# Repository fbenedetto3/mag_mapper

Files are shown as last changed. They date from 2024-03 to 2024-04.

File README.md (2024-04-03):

# MagField-MT Documentation

## Overview
MagField-MT is a low-cost magnetic field mapping platform that can be easily assembled using easily avaliable commercially avaliable components. The plaform is constructed using a Ender 3 (or similar) 3d printer and a Metrolab MagVector MV2 Three-Axis Hall Effect Sensor, and controlled by a computer via a LabView interface. 

## Hardware
All necessary hardware may be printed using the requisite Ender 3 3D printer. [Hardware files](Sensor%20Mounting%20Hardware) are provided in an .stl format for use with any slicing program and .sldprt format to enable modification. M3-25mm bolts and M3 nuts are required to attach the sensor to the mount. 

## Downloading the Magnetic Field Mapper LabVIEW Program

## Using Magnetic Field Mapper LabVIEW Program
To establish a connection between the Arduino, 3D printer, and the LabVIEW program, select the proper COM port for each device and input it into the COM port selection for each device. Select initialize to establish a COM port connection. Ensure the proper COM ports are selected in the event of an error and initialize again.

Custom commands can be sent to the printer, in addition to movements in the movement pane. The distance travelled per movement can be configured in the “Distance” selection and the movement speed of all movements of the printer can be configured in the “Speed” selection. The pathing file can be selected in the “Path File Location” dropdown. Ensure that the file selected is a .csv file with comma delimiters. A MATLAB program that generates pathing files is included in GitHub, but custom paths can easily be generated by the user. The mapping path can be displayed for the user in the mapping path pane.

Before running the mapping scan, ensure that a text file that is empty is selected as previous data will be overwritten. To run the mapping program, press “RUN SCAN”, at which point the program will commence. To exit the mapping program, select “EXIT SCAN”. The same button can also be selected to exit the mapping program not during a scan.

## MATLAB Path Generator
Generates a csv file with magnetic field mapper gird. Inputting gridGenerator(x,y,z,xres,yres,zres) will output a path with resolution being specified for every cardinal direction. Inputting gridGenerator(x, y, z, xres, yres, zres, xCenter, yCenter, zCenter will output a grid with with shifted coordinates around a specified center. This is useful when a scan needs to surround a specific sample. Running the function with no variables will prompt the function to ask user to input xyz scan size and resolution.

## Proper Printing MID
This program uses instrument drivers developed by Jón Schone of Proper Printing. The Marlin Instrument Drivers can be found at https://github.com/properprinting/PPC. The LabVIEW folder contains the drivers, but they can be optionally installed into the LabVIEW program files for use in other programs.

## Arduino Code
The latest version of the program uses [MV2_analog_Mean_Var.ino](Arduino%20Code/MV2%20Analog%20Mean%20Var/MV2_analog_Mean_Var). It operates by calculating the mean and variance of 30 readings after receiving an “M” command over the serial port. The number of readings can be changed in the code by changing the variable “nReads” if the user desires. Additional programs are in the GitHub that automatically send magnetic field data while on, which can be useful during debugging of the sensor. Additional documentation of the sensor is available on https://www.metrolab.com/products/magvector-mv2-magnetometer/.

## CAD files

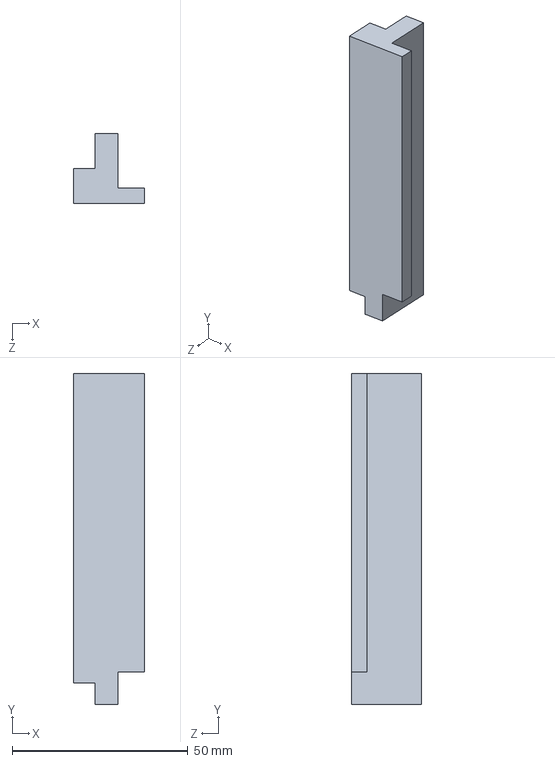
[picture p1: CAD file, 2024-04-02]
Sensor Mounting Hardware/Safety Barrier.SLDPRT
20.1 x 94.2 x 20.0 mm

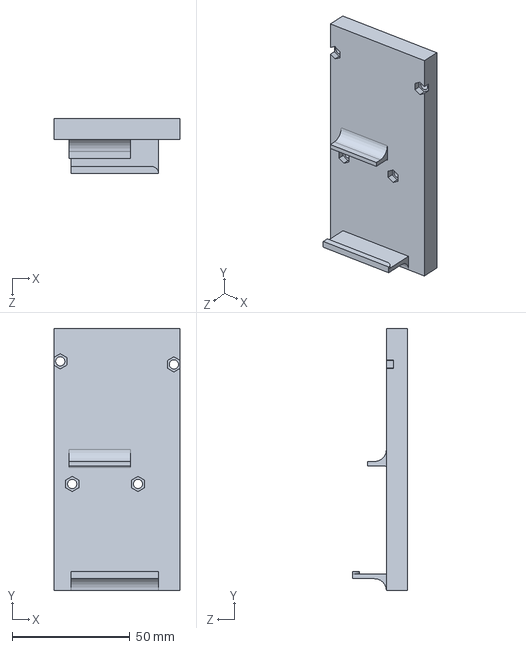
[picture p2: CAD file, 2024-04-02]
Sensor Mounting Hardware/Mount V2.2.SLDPRT
53.4 x 111.3 x 23.4 mm

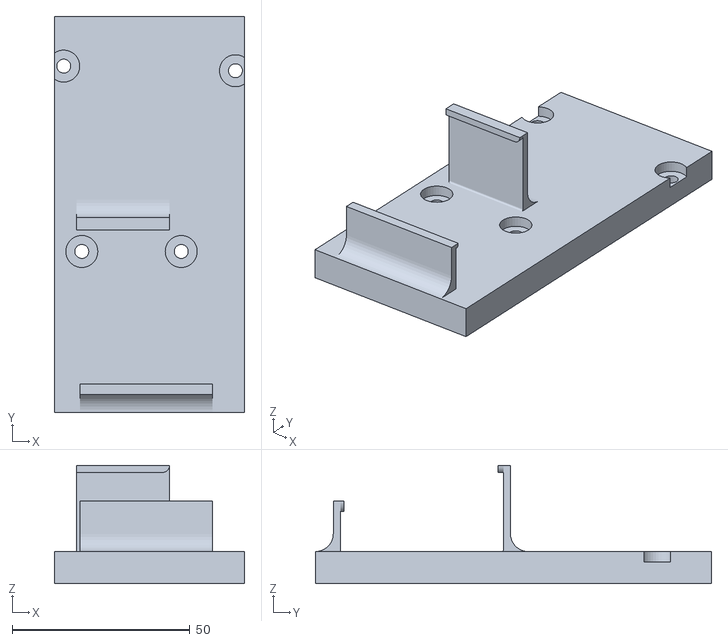
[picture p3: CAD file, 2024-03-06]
Sensor Mounting Hardware/Mount V2.1.STL
53.4 x 111.3 x 33.2

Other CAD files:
Sensor Mounting Hardware/Safety Barrier V1.1.STL

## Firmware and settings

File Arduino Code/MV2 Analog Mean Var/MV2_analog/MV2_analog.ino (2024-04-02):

/*   MV2_analog.ino
 * 
 *   example code how to set and read analog data from 
 * 
 *   METROLAB MV2 3 axis Hall sensor: 
 *   
 *   code for standalone operation 
 *   with an Arduino MEGA or UNO (generic design)
 *   
 *   I did a coarse calibration versus another Hall probe and the values seem to be correct within 5% or better.
 *   Becasue I had to magnetic shield of suitable size I could not check the offsets.
 *   There is a systemtatic difference of 0.5 relative to the calibration data in Table 6 (5V),  
 *   addionally the temperature is also somewhat odd, couldn't calibrate this much.
 *   
 *   Therefore, this code is just an example how to get started (reading all three field components with 10bit resolution
 *   and manually adjustable range). Extended range and other temp. compensations were not tried, but I'm sure you will 
 *   figure out if needed.
 *   
 *   PS: These is also a code for digital operation
 * 
 *   (c) P. Blümler, Physics Uni Mainz, Germany 2022
 *       bluemler@uni-mainz.de
 */
 
 #include <SPI.h> 


#define NDIGITAL_ANALOG_PIN     8
#define VDD_PIN                 A5 
#define A_BX_PIN                A0
#define A_BY_PIN                A1
#define A_BZ_PIN                A2
#define A_TEMPERATURE_PIN       A3
#define A_REF_PIN               A4
#define A_EMR_PIN               2
#define A_INV_PIN               4
#define A_LP_PIN                7

#define A_MA0_PIN               10  //pins on Arduino UNO
#define A_MA1_PIN               11
#define A_RA0_PIN               12
#define A_RA1_PIN               13

/*  
 *  #define A_MA0_PIN               53  //pins on Arduino MEGA
    #define A_MA1_PIN               51
    #define A_RA0_PIN               50
    #define A_RA1_PIN               52
 */

float Vref, Temp,RangeXY,RangeZ;
int ARi,Bxi,Byi,Bzi,Ti;
uint8_t range;

char strX[20]; //at least as long as # of char +1
char strY[20]; //are these too long/short. Idk but seems to work/not matter
char strZ[20]; 
char strVarX[20]; //at least as long as # of char +1
char strVarY[20]; //are these too long/short. Idk but seems to work/not matter
char strVarZ[20]; 
char buffer[50];

int nReads = 30;
float Bx[nReads];
float By[nReads];
float Bz[nReads];




char incomingByte = '0';

void setup() {
    //Configure common pins
    pinMode(NDIGITAL_ANALOG_PIN, OUTPUT);
    pinMode(VDD_PIN, INPUT);
    pinMode(A_BX_PIN, INPUT);
    pinMode(A_BY_PIN, INPUT);
    pinMode(A_BZ_PIN, INPUT);
    pinMode(A_TEMPERATURE_PIN, INPUT);
    pinMode(A_REF_PIN, INPUT);
    pinMode(A_INV_PIN, OUTPUT);
    //Configure option pins
    pinMode(A_MA0_PIN, OUTPUT);
    pinMode(A_MA1_PIN, OUTPUT);
    pinMode(A_RA0_PIN, OUTPUT);
    pinMode(A_RA1_PIN, OUTPUT);
    pinMode(A_LP_PIN, OUTPUT);
    pinMode(A_EMR_PIN, OUTPUT);
   
    digitalWrite(NDIGITAL_ANALOG_PIN, HIGH); //enable Analog mode
    // Initialize all other controls to LOW (logic 0)
    digitalWrite(A_INV_PIN, LOW);
    digitalWrite(A_MA0_PIN, LOW);
    digitalWrite(A_MA1_PIN, LOW);
    digitalWrite(A_RA0_PIN, LOW);
    digitalWrite(A_RA1_PIN, LOW);
    digitalWrite(A_LP_PIN, LOW);
    digitalWrite(A_EMR_PIN, LOW);
    Serial.begin(9600);
}

void AnalogSetOptions(uint8_t Options)  //Set options bits : RA0, RA1, MA0, MA1, LP, INV, EMR
{   digitalWrite(A_RA0_PIN, bitRead(Options, 0));
    digitalWrite(A_RA1_PIN, bitRead(Options, 1));
    digitalWrite(A_MA0_PIN, bitRead(Options, 2));
    digitalWrite(A_MA1_PIN, bitRead(Options, 3));
    digitalWrite(A_LP_PIN,  bitRead(Options, 4));
    digitalWrite(A_INV_PIN, bitRead(Options, 5));
    digitalWrite(A_EMR_PIN, bitRead(Options, 6));
}


void loop() {
        for (int i = 0; i < nReads; i++){
                // SELECT RANGE MANUALLY
        range=0;    // 0 = +/- 100 mT, 1 = +/- 300 mT, 2 = +/- 1 T, 3 = +/- 3 T

        //Serial.print(" >>> Analog Mode:   range: ");
        if (Serial)
        switch (range){
          case 0:
            RangeXY=18.18;  //range from table 6 (5V)
            RangeZ=20.73;
            //Serial.println("+/- 100 mT");
            break;
          case 1:
            RangeXY=6,27;  //range from table   6 (5V)
            RangeZ=7.04;
            //Serial.println("+/- 300 mT");
            break;
          case 2:
            RangeXY=1.89;  //range from table  6 (5V)
            RangeZ=2.13;
            //Serial.println("+/- 1000 mT");
            break;
            case 3:
          default:
            RangeXY=0.62;  //range from table  6 (5V)
            RangeZ=0.72;
            //Serial.println("+/- 3000 mT");
            break;
          }
          // here only the first 2 bits (RA0 and RA1) are set 
          AnalogSetOptions(range); // Set OPTIONS bits (RA0, RA1, MA0, MA1, LP, INV, EMR)



//Wait to see if read command is sent
 if (Serial.available() > 0) {
    // read the incoming byte:
    incomingByte = Serial.read();

    if (incomingByte == 'M') {


          ARi=analogRead(A_REF_PIN);
          Bxi=analogRead(A_BX_PIN);
          Byi=analogRead(A_BY_PIN);
          Bzi=analogRead(A_BZ_PIN);
          Ti=analogRead(A_TEMPERATURE_PIN);
          // conversion to voltages(without extended measuring range)
          Vref=float(ARi)/511*5000; // reference voltage [mV]
          
          // 10 bit Arduino ADC * 5000 mV and additional mV offset

          Bx[i] = float(Bxi-ARi-3.2)/511*5000/RangeXY/2;
          By[i] = float(Byi-ARi-4.5)/511*5000/RangeXY/2 ;
          Bz[i]=float(Bzi-ARi)/511*5000/RangeZ/2;
          Serial.println(Bx[i], 1);

      }
      float BxSum = 0;
      float BySum = 0;
      float BzSum = 0;
      float BxSumSq = 0;
      float BySumSq = 0;
      float BzSumSq = 0;

      for (int i = 0; i < nReads; i++){
        BxSum += Bx[i];
        BySum += By[i];
        BzSum += Bz[i];


      }

      float meanX = 0;
      float meanY = 0;
      float meanZ = 0;
      float varX = 0;
      float varY = 0;
      float varZ = 0;

      meanX = BxSum/nReads;
      Serial.print(meanX, 3);
      Serial.print(", ");
      meanY = BySum/nReads;
      Serial.print(meanY, 3);
      Serial.print(", ");
      meanZ = BzSum/nReads;
      Serial.print(meanZ, 3);
      Serial.println();
        BxSum = 0;
        BySum = 0;
        BzSum = 0;








      // for (int i = 0; i < nReads; i++){
      //   BxSumSq += (Bx[i] - meanX)*(Bx[i] - meanX);
      //   //Serial.println(BxSumSq,1);
      //   BySumSq += (By[i] - meanY)*(By[i] - meanY);
      //   BzSumSq += (Bz[i] - meanZ)*(Bz[i] - meanZ);
      // }
      // varX = BxSumSq/(nReads-1);
      // Serial.print(varX, 3);
      // Serial.print(", ");
      // varY = BxSumSq/(nReads-1);
      // Serial.print(varY, 3);
      // Serial.print(", ");
      // varZ = BxSumSq/(nReads-1);
      // Serial.println(varZ, 3);
      // dtostrf(meanX, -5, 7, strX); 
      //  dtostrf(meanY, -5, 7, strY); 
      //  dtostrf(meanZ, -5, 7, strZ); 
      //  dtostrf(meanX, -5, 7, strVarX); 
      //  dtostrf(meanY, -5, 7, strVarY); 
      //  dtostrf(meanZ, -5, 7, strVarZ); 
      //sprintf(buffer, "%s, %s, %s, %s, %s, %s", strX, strY, strZ, strVarX, strVarY, strVarZ);
       
    }
  }
}

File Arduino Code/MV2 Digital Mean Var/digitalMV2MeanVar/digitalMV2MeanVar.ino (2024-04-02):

/*   MV2_digital.ino
 * 
 *   example code how to set and read data from 
 * 
 *   METROLAB MV2 3 axis Hall sensor: 
 *   
 *   code for standalone operation 
 *   with an Arduino MEGA or UNO (generic design)
 *   
 *   I did a coarse calibration versus another Hall probe and the values seem to be correct within 5% or better.
 *   Becasue I had to magnetic shield of suitable size I could not check the offsets.
 *   The temperature is also somewhat odd, because the values given in the data sheet (table 10) gave strange values.
 *   
 *   Therefore, this code is just an example how to get started (reading all three field components with 16bit resolution
 *   and manually adjustable range). Extended range and other temp. compensations were not tried, but I'm sure you will 
 *   figure out if needed.
 *   
 *   PS: These is also a code for analog operation
 * 
 *   (c) P. Blümler, Physics Uni Mainz, Germany 2022
 *       bluemler@uni-mainz.de
 */
    const int xPin = A0; 
    const int yPin = A1;
    const int zPin = A2;
    float xZero = digitalRead(xPin);
    float yZero = digitalRead(yPin);
    float zZero = digitalRead(zPin);

#include <SPI.h> 
#define NDIGITAL_ANALOG_PIN     8
#define D_DR_PIN                2
#define D_INIT_PIN              7
#define D_CHIP_SELECT_PIN       10
#define D_SPI_MOSI                11
#define D_SPI_MISO              12
#define D_SPI_CLK               13

const byte READ = 0x1C;   //Read address MV2     
const byte WRITE = 0x2C;  //Write address MV2
float Temp,RangeXY,RangeZ;
uint16_t data;
int range_set;
byte RA_byte;

char strX[20]; //at least as long as # of char +1
char strY[20]; //are these too long/short. Idk but seems to work/not matter
char strZ[20]; 
char strVarX[20]; //at least as long as # of char +1
char strVarY[20]; //are these too long/short. Idk but seems to work/not matter
char strVarZ[20]; 
char buffer[50];

const int nReads = 30;
float Bx[nReads];
float By[nReads];
float Bz[nReads];

char incomingByte = '0';


void setup() {
    Serial.begin(9600);
    digitalWrite(NDIGITAL_ANALOG_PIN,LOW); //Select digital mode
    SPI.begin();
    pinMode(D_DR_PIN , INPUT);
    pinMode(D_CHIP_SELECT_PIN, OUTPUT);
    writeRegister(0xC1, 0x00);  //init
    writeRegister(0x2C, 0x2C);  //set to read Bx 3T 16 bit (to init)
    writeRegister(0x2D, 0x02);  //permanent MISO
    writeRegister(0x2E, 0x08);  //temp. comp 0
    delay(100); }
    

//little routine to read a SPI register 
uint16_t readRegister(byte Register, byte Value) {
   uint16_t result = 0;   // result to return
   uint16_t dataToSend = (Register << 8) | Value;
   digitalWrite(D_CHIP_SELECT_PIN, LOW);
   result = SPI.transfer16(dataToSend);
   digitalWrite(D_CHIP_SELECT_PIN, HIGH);
   return (result);}


//little routine to write a SPI register 
void writeRegister(byte Register, byte Value) {
   uint16_t dataToSend = (WRITE << 8) | Register ;
   digitalWrite(D_CHIP_SELECT_PIN, LOW);
   SPI.transfer16(dataToSend); //Send register location
   SPI.transfer(Value);  //Send value to record into register
   digitalWrite(D_CHIP_SELECT_PIN, HIGH);}
 
void loop() {
  float Bxs = 0;
  float Bys = 0;
  float Bzs = 0;
  // SELECT RANGE MANUALLY
  range_set=1; // 0 = +/- 100 mT, 1 = +/- 300 mT, 2 = +/- 1 T, 3 = +/- 3 T

  //Serial.print(" >>> Digital Mode:   range: ");
  
  switch (range_set){ //offsets need to be detemined experimentally
    case 0:
      RA_byte=0x00;
      RangeXY=267;  //range from table 10
      RangeZ=289;
     // Serial.println("+/- 100 mT");
      break;
    case 1:
      RA_byte=0x04;
      RangeXY=91.2;  //range from table 10
      RangeZ=98.5;
      //Serial.println("+/- 300 mT");
      break;
    case 2:
      RA_byte=0x08;
      RangeXY=27.6;  //range from table 10
      RangeZ=29.5;
      //Serial.println("+/- 1000 mT");
      break;
    default:
      RA_byte=0x0C;
      RangeXY=9.1;  //range from table 10
      RangeZ=10;
      //Serial.println("+/- 3000 mT");
      break;
  }

 if (Serial.available() > 0) {
    // read the incoming byte:
    incomingByte = Serial.read();

      if (incomingByte == 'M') {
        Serial.println("M recieved");
        for (int i = 0; i < nReads; i++){
          data = readRegister(0x2C, 0x21+RA_byte);
          Bx[i] =((float(data)-32768+280)/RangeXY);
          data = readRegister(0x2C, 0x22+RA_byte);
          By[i] =((float(data)-32768+385)/RangeXY);
          data = readRegister(0x2C, 0x23+RA_byte);
          Bz[i] =((float(data)-32768-125)/RangeZ);
          delay(10);
        }
        float BxSum = 0;
        float BySum = 0;
        float BzSum = 0;
        float varXSum = 0;
        float varYSum = 0;
        float varZSum = 0;

        for (int i = 0; i < nReads; i++){
          BxSum += Bx[i];
          BySum += By[i];
          BzSum += Bz[i];
        }

        float meanX = 0;
        float meanY = 0;
        float meanZ = 0;
        float varX = 0;
        float varY = 0;
        float varZ = 0;

        meanX = BxSum/nReads;
        Serial.print(meanX, 5);
        Serial.print(", ");
        meanY = BySum/nReads;
        Serial.print(meanY, 5);
        Serial.print(", ");
        meanZ = BzSum/nReads;
        Serial.print(meanZ, 5);
        Serial.print(", ");

        for (int i = 0; i < nReads; i++){
            varXSum += (Bx[i]/RangeXY/2 - meanX)*(Bx[i]/RangeXY/2 - meanX);
            varYSum += (By[i]/RangeXY/2 - meanY)*(By[i]/RangeXY/2 - meanY);
            varZSum += (Bz[i]/RangeZ/2 - meanZ)*(Bz[i]/RangeZ/2 - meanZ);
          }

        varX = varXSum/(nReads-1);
        Serial.print(varX, 5);
        Serial.print(", ");
        varY = varYSum/(nReads-1);
        Serial.print(varY, 5);
        Serial.print(", ");
        varZ = varZSum/(nReads-1);
        Serial.println(varZ, 5);

    }
 }
     else {
      if (digitalRead(D_DR_PIN) == HIGH) { //if ready
        data = readRegister(0x2C, 0x21+RA_byte); 
        Bxs = (float(data)-32768)/RangeXY;
        Serial.print(Bxs, 5);
        Serial.print(", ");
        data = readRegister(0x2C, 0x22+RA_byte);
        Bys =((float(data)-32768+385)/RangeXY);
        Serial.print(Bys, 3);
        Serial.print(", ");
        data = readRegister(0x2C, 0x23+RA_byte);
        Bzs =((float(data)-32768-125)/RangeZ);
        Serial.println(Bzs, 3);
        delay(200);
      }
      else { 
        Serial.println("Not Ready");
        delay(100);
      }
    }
}

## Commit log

2024-04-02 Published Files Upload
    [Mount V2.1.STL, Mount V2.2.SLDPRT, Safety Barrier V1.1.STL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]
2024-04-03 Marlin Driver License Add
2024-04-03 Update LICENSE.txt to reflect marlin instrument driver only
